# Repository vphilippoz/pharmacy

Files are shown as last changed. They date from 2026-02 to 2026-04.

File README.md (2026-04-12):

# Pharmacy Cross Display
<p align="left">
    <a href="https://github.com/vphilippoz/pharmacy/releases/tag/v1.1" alt="Latest stable version">
        </a>
</p>

A miniature pharmacy cross display made of LED matrices.

<p align="center">
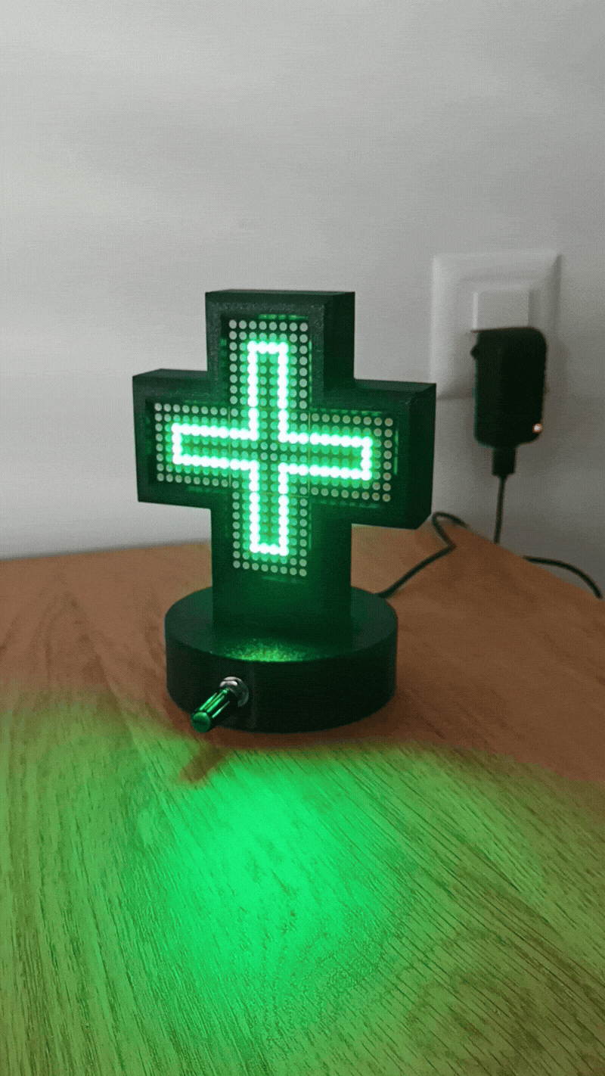
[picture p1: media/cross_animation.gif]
    
</p>

This is a fun project to build and decorate you home, or bring at a rave party! The software runs on a ESP32 and controls 5 square LED matrices.

# Features

In its current version, the project has:

- 8 animations
- Button to switch between animations
- Potentiometer to tune brightness and animation speed
- Python script to easily create animation bitmap from a .gif file
- Excel file to easily create animation bitmap from a drawing (in excel file)

Available animations are:

1. Always ON
1. Blink
1. Random (White noise)
1. Cross shrinking
1. Girl dance
1. Fortnite dance
1. Spinning fish
1. Spiral

# Usage

Plug the power connector. The device starts automatically. A short press on the button changes the animation. Turning the knob allows to tune the animation speed. One cycle is between 80 BPM and 250 BPM. When holding the button, the knob controlls the display brightness.

# BOM

This list is not intended to be a shopping list. It enumerates everything needed to make the Pharmacy Cross Display, but use what you have and adapt the design as needed.

## Electronics

<p align="center">
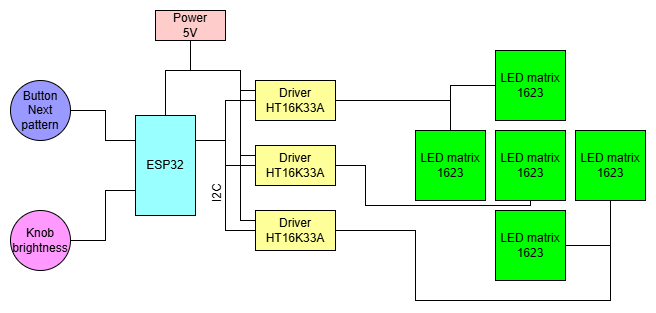
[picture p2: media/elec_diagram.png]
    
</p>

- 5V power supply
- Custom-made PCBs (one of each)
- ESP32-C6-DevKit
- 3 HT16K33 modules (Adafruit 1427)
- 5 green LED matrices (Adafruit 1623)
- 1 10kOhm rotary potentiometer
- 1 THT 10kOhm resistor
- 1 push button
- 1 barrel power connector
- Cables
- Headers for ESP32, HT16k33 and peripherals

## Casing

- 4-parts 3D printed custom casing. I printed mine in black PETG.
- 2 M2.5x4 socket head cap screws
- 10 M2.5x8 socket head cap screws
- Optional: 6 M2.5 washers

## Tools

- 3D printer
- 2mm allen key
- Soldering iron
- Solder
- Set of pliers

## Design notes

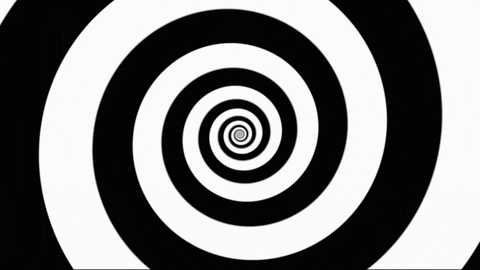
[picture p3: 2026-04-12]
media/gifs/spiral.gif

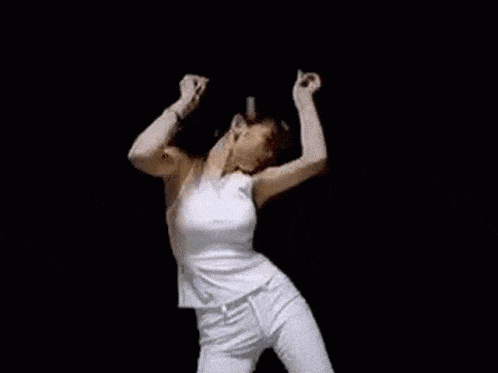
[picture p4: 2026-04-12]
media/gifs/girl.gif

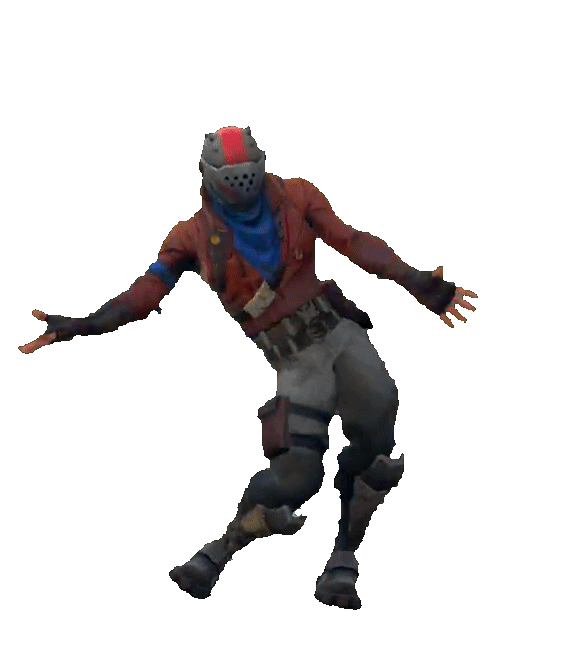
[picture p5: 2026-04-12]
media/gifs/fortnite.gif

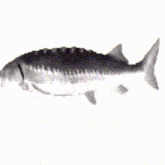
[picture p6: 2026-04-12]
media/gifs/fish.gif

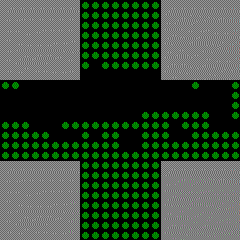
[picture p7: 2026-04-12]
Software/animation_library/fish_animation.gif

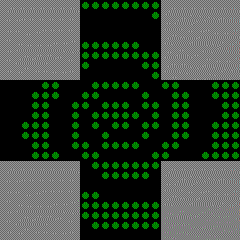
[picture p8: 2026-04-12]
Software/animation_library/spiral_animation.gif

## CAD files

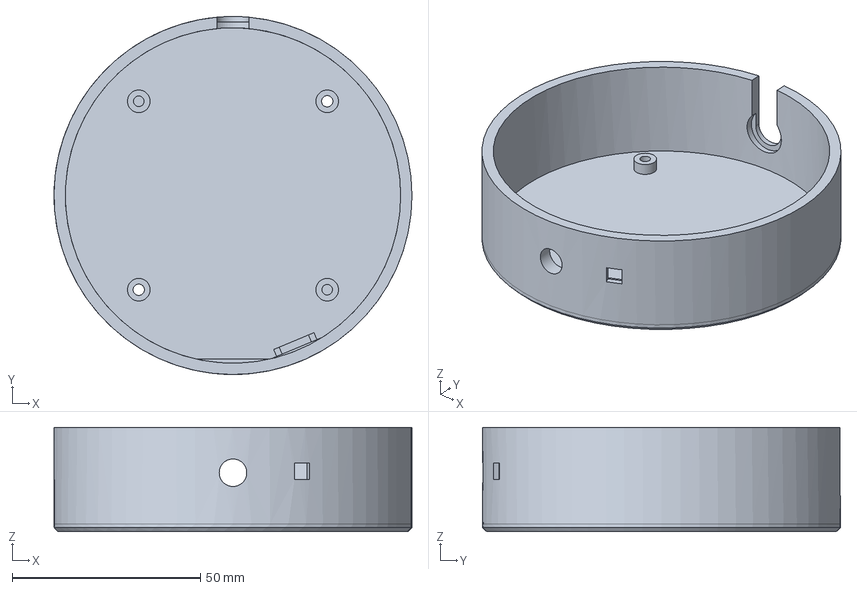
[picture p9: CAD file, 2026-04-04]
3D/case_logic_bottom.FCStd
95.0 x 95.0 x 27.6 mm

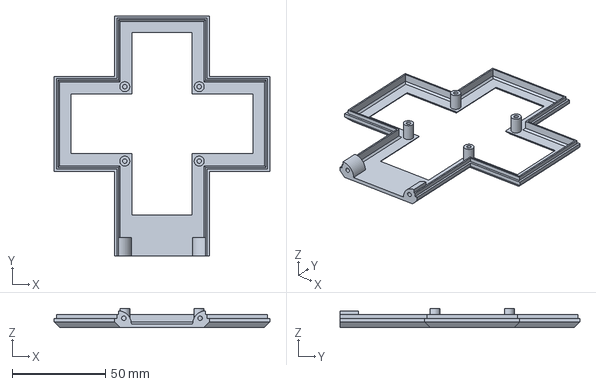
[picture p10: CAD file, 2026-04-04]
3D/case_cross_top.FCStd
116.0 x 129.0 x 10.3 mm

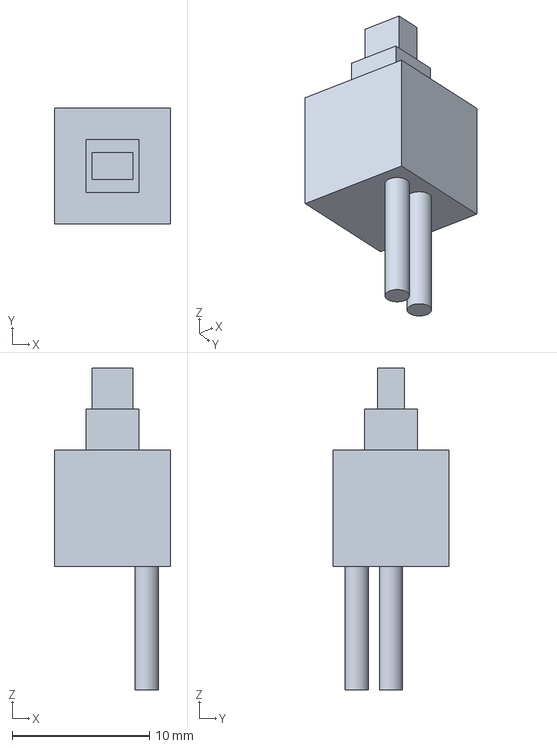
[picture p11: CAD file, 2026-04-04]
3D/button.FCStd
8.50 x 8.50 x 23.5 mm

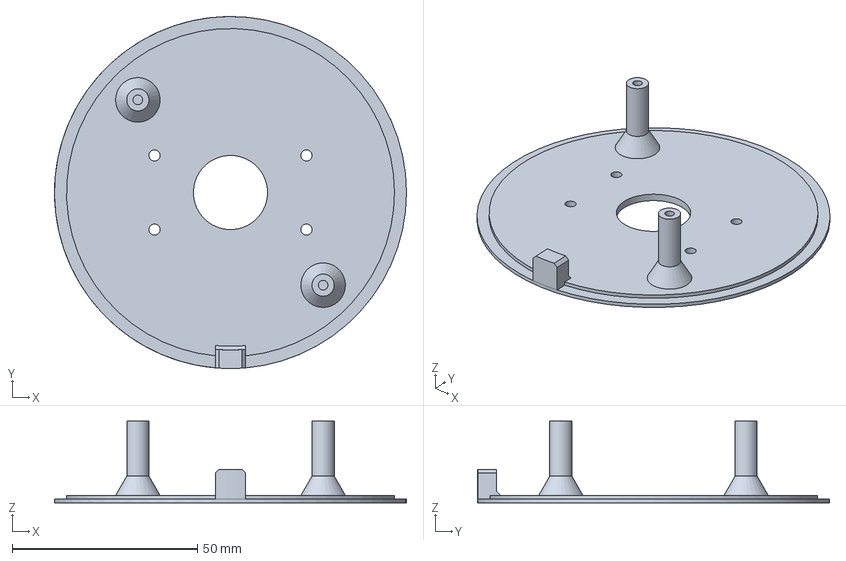
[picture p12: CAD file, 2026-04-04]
3D/case_logic_top.FCStd
95.0 x 95.0 x 22.0 mm

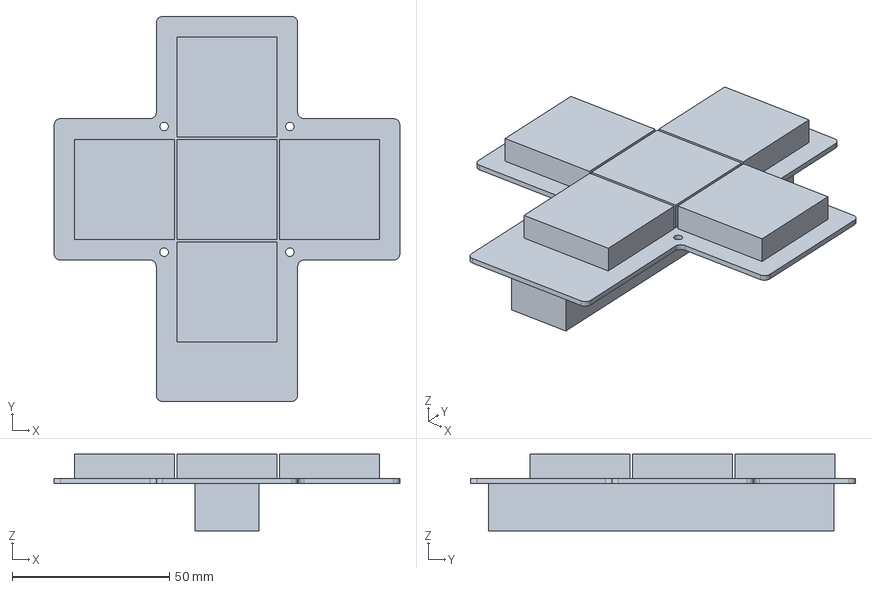
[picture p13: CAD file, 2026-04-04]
3D/PCB_cross.FCStd
110.0 x 122.5 x 24.4 mm

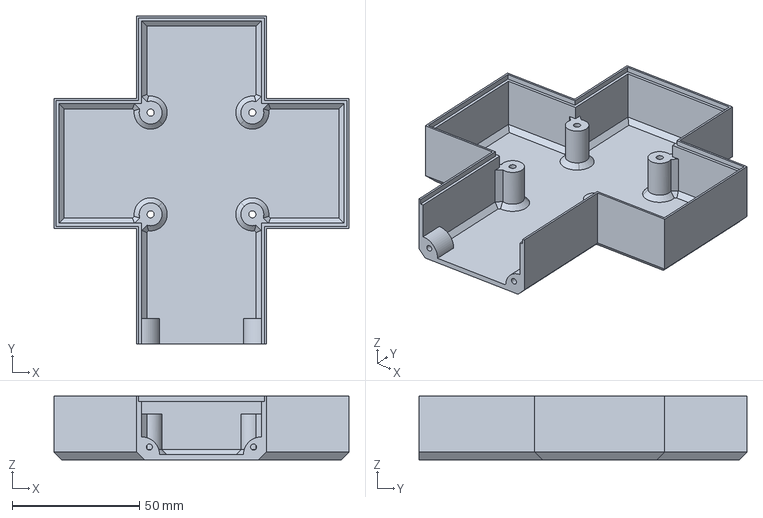
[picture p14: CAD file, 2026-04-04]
3D/case_cross_bottom.FCStd
116.0 x 129.0 x 25.0 mm

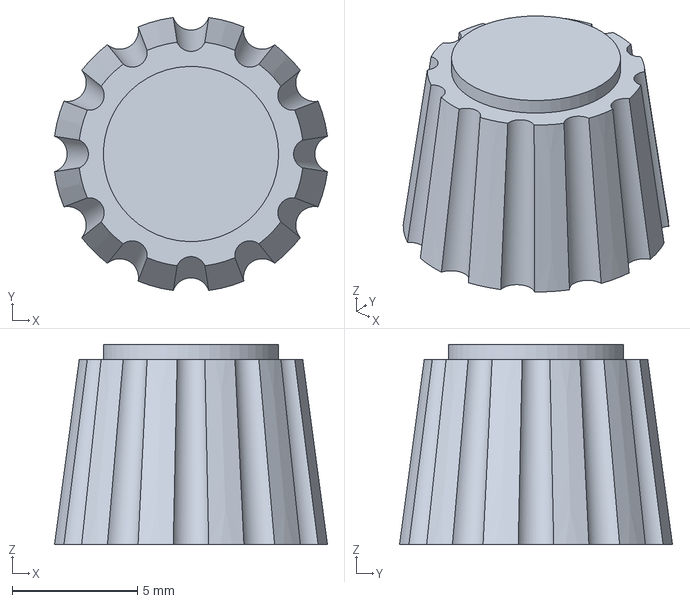
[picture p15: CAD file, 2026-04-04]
3D/knob_btn.FCStd
10.9 x 10.9 x 8.00 mm

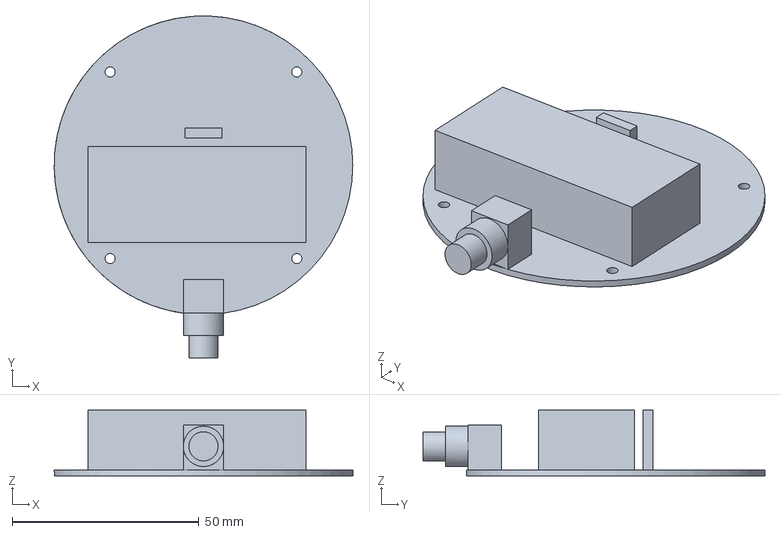
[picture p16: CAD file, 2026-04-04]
3D/PCB_logic.FCStd
80.0 x 91.6 x 17.6 mm

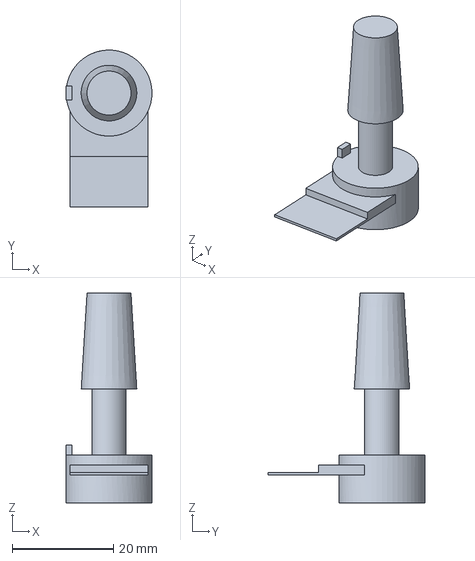
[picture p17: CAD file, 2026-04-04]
3D/potentiometer.FCStd
17.0 x 31.0 x 41.5 mm

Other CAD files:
3D/asm.FCStd
3D/case_cross_bottom.stl
3D/case_cross_top.stl
3D/case_logic_bottom.stl
3D/case_logic_top.stl

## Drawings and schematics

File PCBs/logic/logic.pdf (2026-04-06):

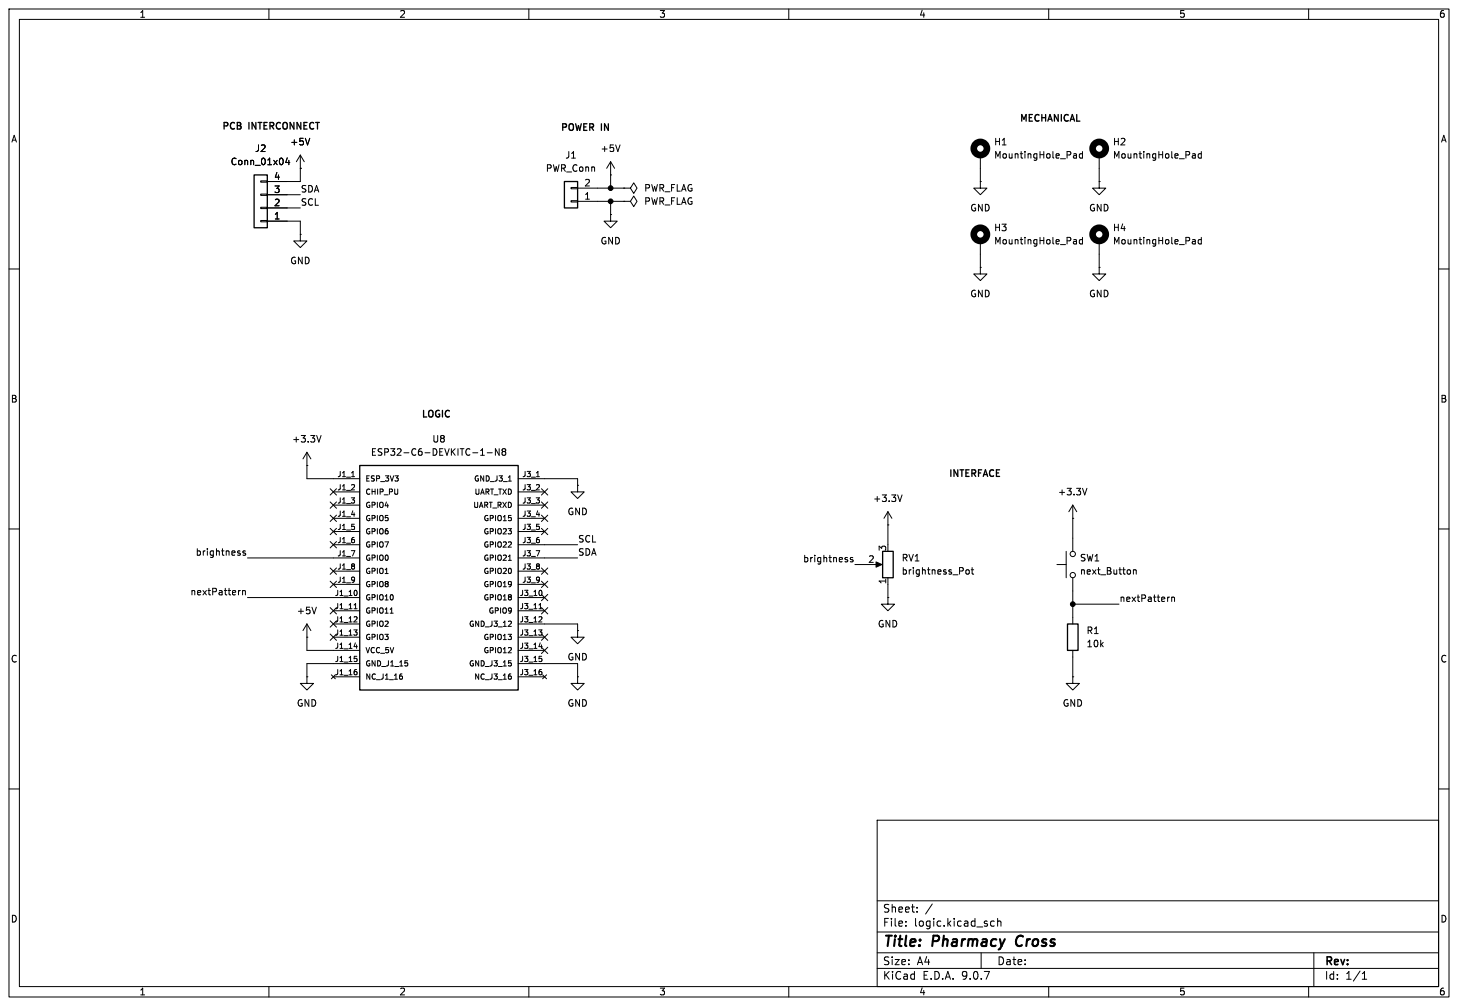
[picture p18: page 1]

File: logic.kicad_sch Sheet: /
Id: 1/1 Title: Pharmacy Cross

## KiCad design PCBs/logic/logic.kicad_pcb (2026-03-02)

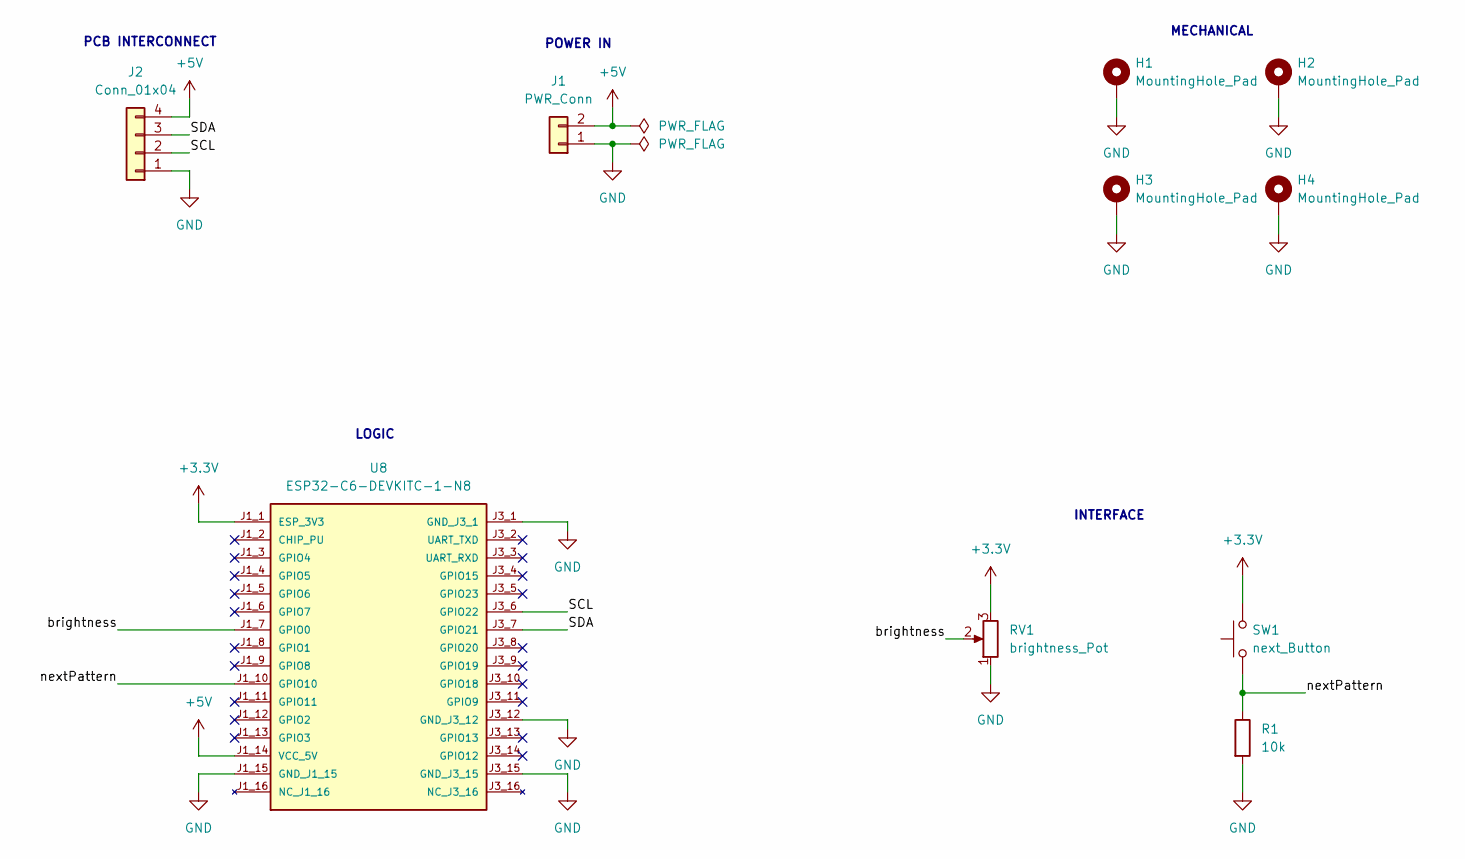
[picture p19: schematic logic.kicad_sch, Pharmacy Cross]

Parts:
H1, H2, H3, H4: MountingHole_Pad; MountingHole_2.7mm_M2.5_ISO7380_Pad
J1: PWR_Conn; BarrelJack_Horizontal
J2: Conn_01x04; PinHeader_1x04_P2.54mm_Vertical
R1: 10k; R_Axial_DIN0207_L6.3mm_D2.5mm_P10.16mm_Horizontal
RV1: brightness_Pot; PinHeader_1x03_P2.54mm_Vertical
SW1: next_Button; PinHeader_1x02_P2.54mm_Vertical
U8: ESP32-C6-DEVKITC-1-N8; MODULE_ESP32-C6-DEVKITC-1-N8; PARTREV 1.3

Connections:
+3.3V: RV1.3, SW1.2, U8.J1_1 (ESP_3V3)
+5V: J1.2, J2.4, U8.J1_14 (VCC_5V)
/SCL: J2.2, U8.J3_6 (GPIO22)
/SDA: J2.3, U8.J3_7 (GPIO21)
/brightness: RV1.2, U8.J1_7 (GPIO0)
/nextPattern: R1.1, SW1.1, U8.J1_10 (GPIO10)
GND: H1.1, H2.1, H3.1, H4.1, J1.1, J2.1, R1.2, RV1.1, U8.J1_15 (GND_J1_15), U8.J3_1 (GND_J3_1), U8.J3_12 (GND_J3_12), U8.J3_15 (GND_J3_15)

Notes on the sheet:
LOGIC
PCB INTERCONNECT
POWER IN
INTERFACE
MECHANICAL

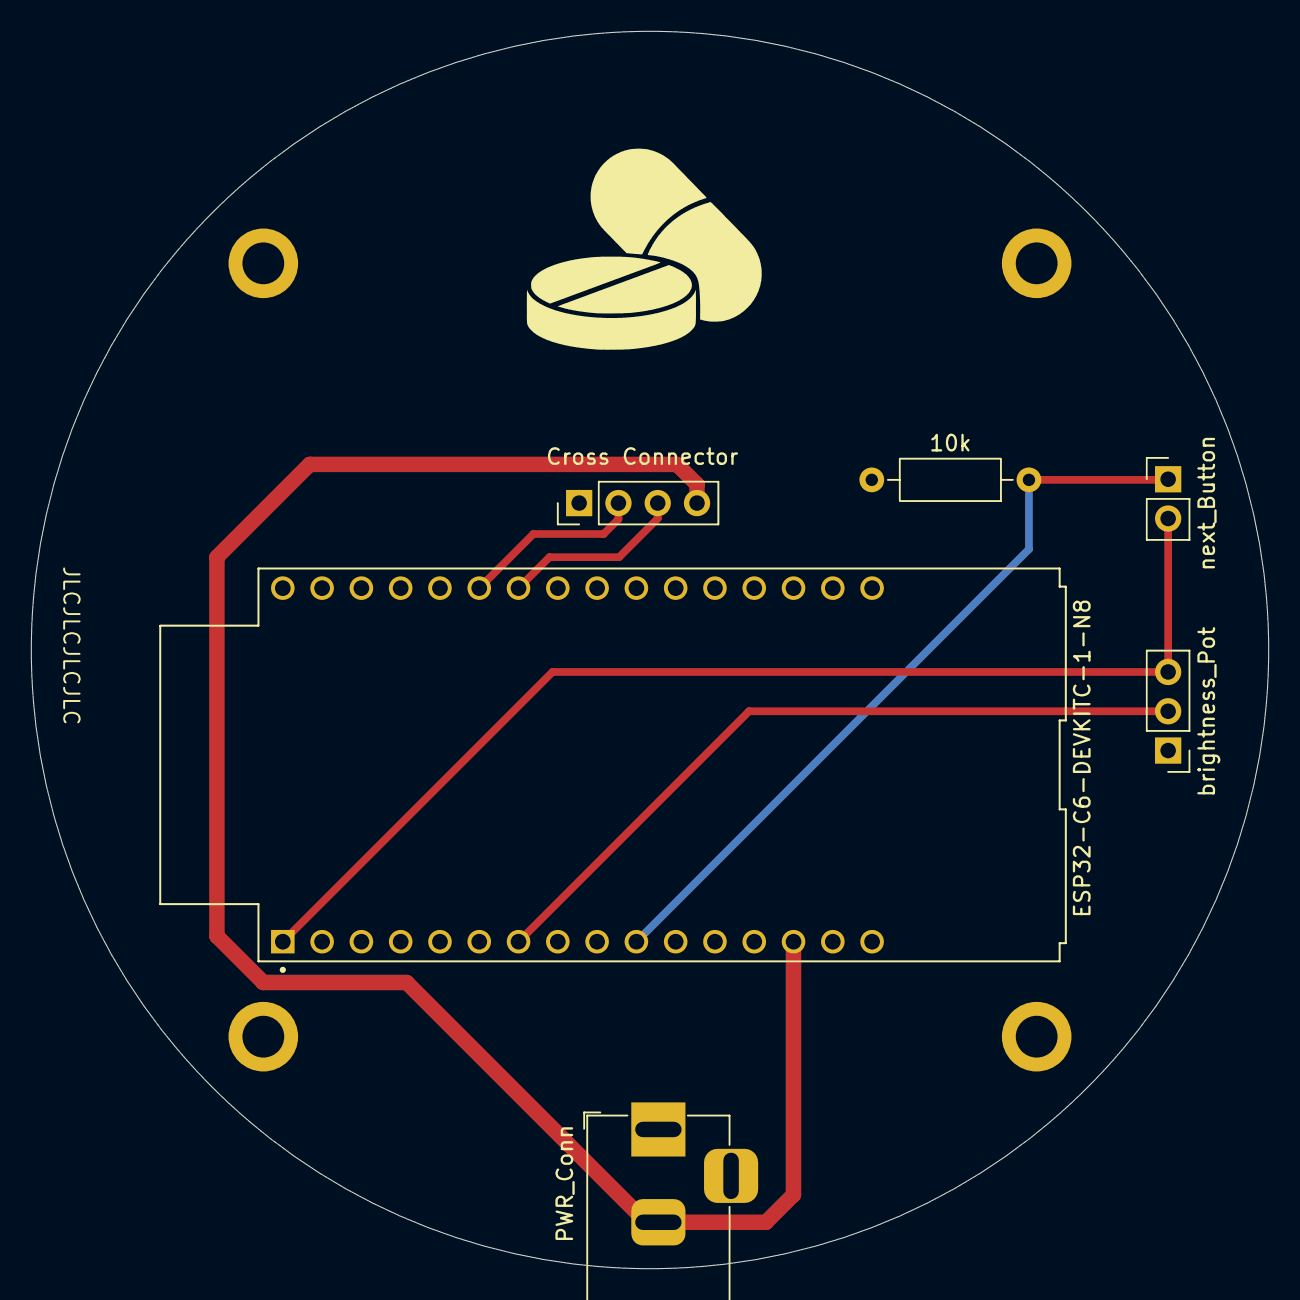
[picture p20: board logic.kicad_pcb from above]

Board: 2 copper layers, 80.0 x 80.0 mm, 10 parts (0 on the bottom side), 7 nets.

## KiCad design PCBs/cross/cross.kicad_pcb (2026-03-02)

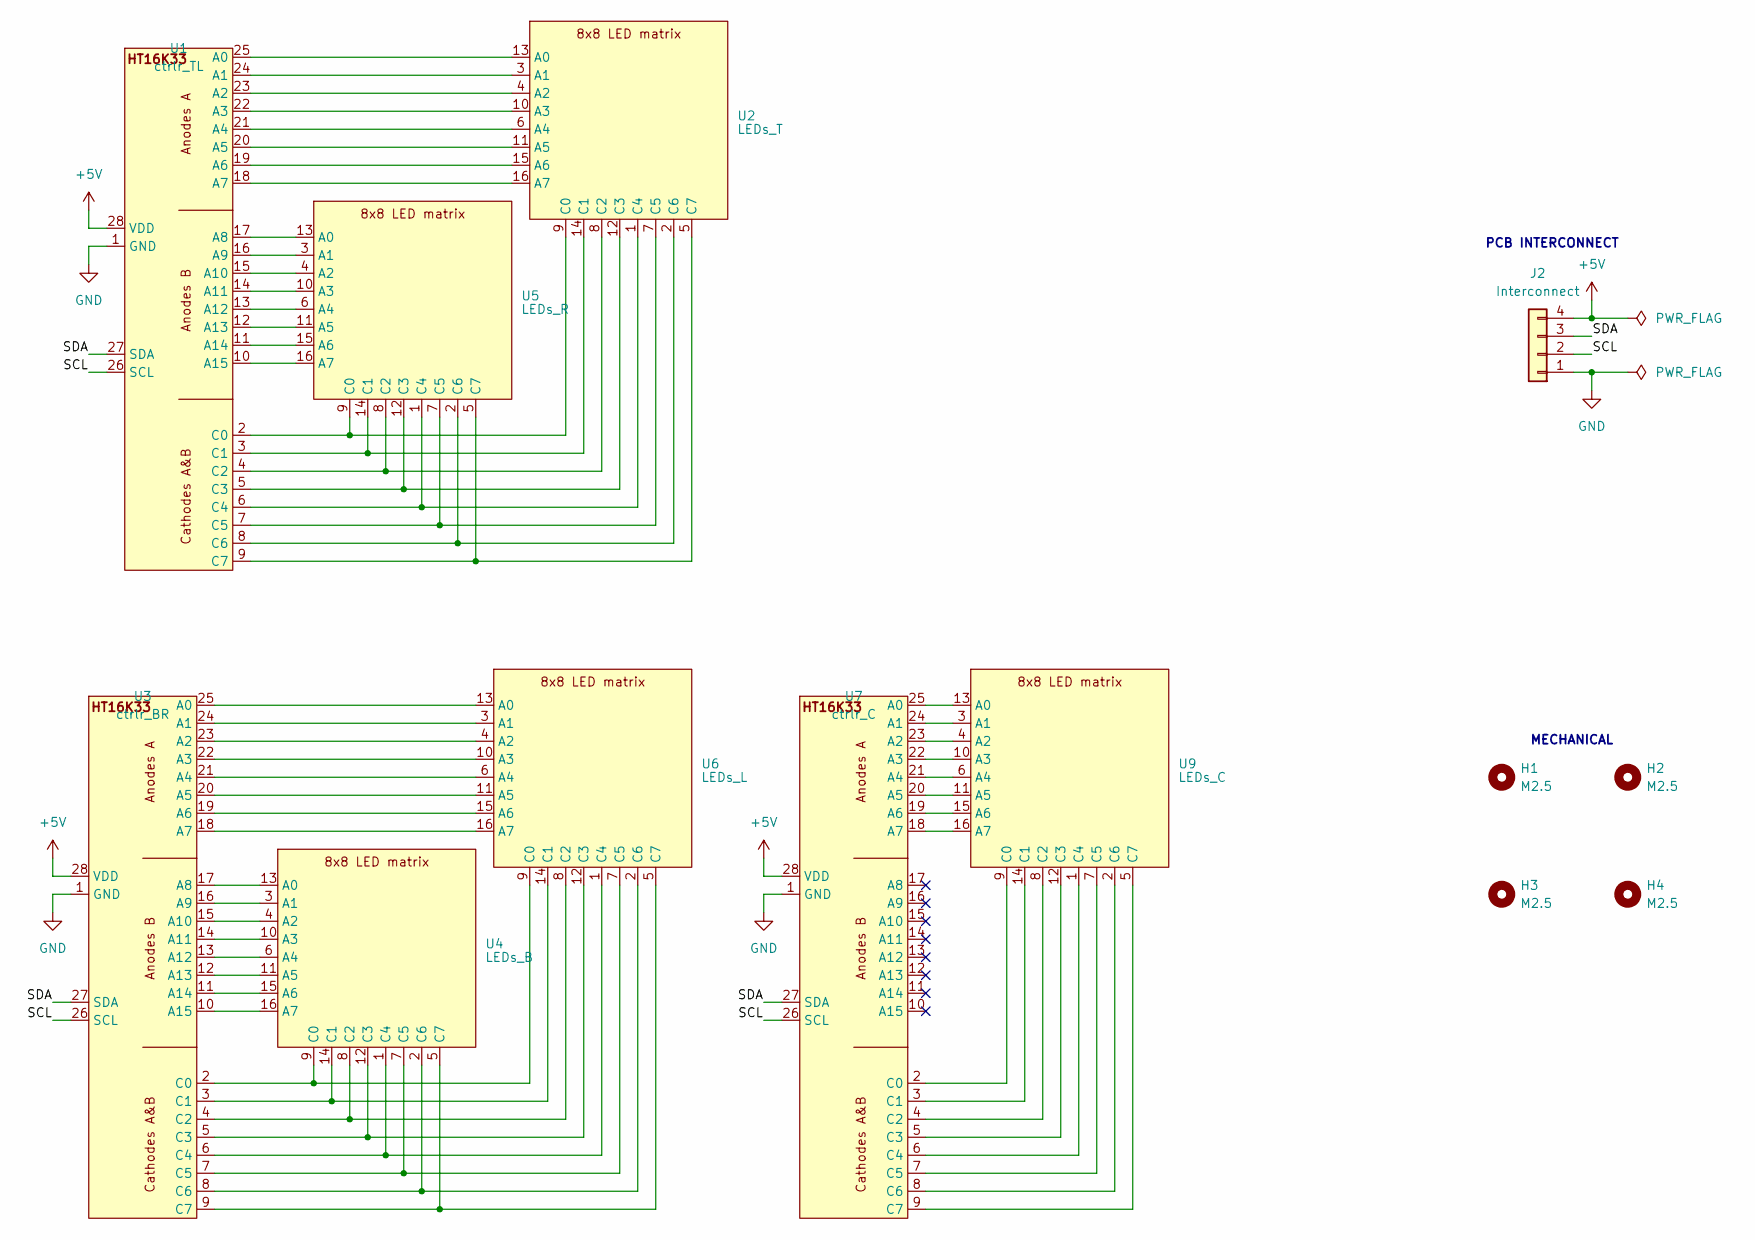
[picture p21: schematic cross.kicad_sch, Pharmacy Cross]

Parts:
H1, H2, H3, H4: M2.5; MountingHole_2.7mm_M2.5
J2: Interconnect; PinHeader_1x04_P2.54mm_Vertical
U1: ctrlr_TL; HT16K33
U2: LEDs_T; KWM-30881
U3: ctrlr_BR; HT16K33
U4: LEDs_B; KWM-30881
U5: LEDs_R; KWM-30881
U6: LEDs_L; KWM-30881
U7: ctrlr_C; HT16K33
U9: LEDs_C; KWM-30881

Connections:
+5V: J2.4, U1.28 (VDD), U3.28 (VDD), U7.28 (VDD)
/SCL: J2.2, U1.26 (SCL), U3.26 (SCL), U7.26 (SCL)
/SDA: J2.3, U1.27 (SDA), U3.27 (SDA), U7.27 (SDA)
GND: J2.1, U1.1 (GND), U3.1 (GND), U7.1 (GND)
unnamed: U1.25 (A0), U2.13 (A0)
unnamed: U1.24 (A1), U2.3 (A1)
unnamed: U1.23 (A2), U2.4 (A2)
unnamed: U1.22 (A3), U2.10 (A3)
unnamed: U1.21 (A4), U2.6 (A4)
unnamed: U1.20 (A5), U2.11 (A5)
unnamed: U1.19 (A6), U2.15 (A6)
unnamed: U1.18 (A7), U2.16 (A7)
unnamed: U1.17 (A8), U5.13 (A0)
unnamed: U1.16 (A9), U5.3 (A1)
unnamed: U1.15 (A10), U5.4 (A2)
unnamed: U1.14 (A11), U5.10 (A3)
unnamed: U1.13 (A12), U5.6 (A4)
unnamed: U1.12 (A13), U5.11 (A5)
unnamed: U1.11 (A14), U5.15 (A6)
unnamed: U1.10 (A15), U5.16 (A7)
unnamed: U1.2 (C0), U2.9 (C0), U5.9 (C0)
unnamed: U1.3 (C1), U2.14 (C1), U5.14 (C1)
unnamed: U1.4 (C2), U2.8 (C2), U5.8 (C2)
unnamed: U1.5 (C3), U2.12 (C3), U5.12 (C3)
unnamed: U1.6 (C4), U2.1 (C4), U5.1 (C4)
unnamed: U1.7 (C5), U2.7 (C5), U5.7 (C5)
unnamed: U1.8 (C6), U2.2 (C6), U5.2 (C6)
unnamed: U1.9 (C7), U2.5 (C7), U5.5 (C7)
unnamed: U3.25 (A0), U6.13 (A0)
unnamed: U3.24 (A1), U6.3 (A1)
unnamed: U3.23 (A2), U6.4 (A2)
unnamed: U3.22 (A3), U6.10 (A3)
unnamed: U3.21 (A4), U6.6 (A4)
unnamed: U3.20 (A5), U6.11 (A5)
unnamed: U3.19 (A6), U6.15 (A6)
unnamed: U3.18 (A7), U6.16 (A7)
unnamed: U3.17 (A8), U4.13 (A0)
unnamed: U3.16 (A9), U4.3 (A1)
unnamed: U3.15 (A10), U4.4 (A2)
unnamed: U3.14 (A11), U4.10 (A3)
unnamed: U3.13 (A12), U4.6 (A4)
unnamed: U3.12 (A13), U4.11 (A5)
unnamed: U3.11 (A14), U4.15 (A6)
unnamed: U3.10 (A15), U4.16 (A7)
unnamed: U3.2 (C0), U4.9 (C0), U6.9 (C0)
unnamed: U3.3 (C1), U4.14 (C1), U6.14 (C1)
unnamed: U3.4 (C2), U4.8 (C2), U6.8 (C2)
unnamed: U3.5 (C3), U4.12 (C3), U6.12 (C3)
unnamed: U3.6 (C4), U4.1 (C4), U6.1 (C4)
unnamed: U3.7 (C5), U4.7 (C5), U6.7 (C5)
unnamed: U3.8 (C6), U4.2 (C6), U6.2 (C6)
unnamed: U3.9 (C7), U4.5 (C7), U6.5 (C7)
unnamed: U7.25 (A0), U9.13 (A0)
unnamed: U7.24 (A1), U9.3 (A1)
unnamed: U7.23 (A2), U9.4 (A2)
unnamed: U7.22 (A3), U9.10 (A3)
unnamed: U7.21 (A4), U9.6 (A4)
unnamed: U7.20 (A5), U9.11 (A5)
unnamed: U7.19 (A6), U9.15 (A6)
unnamed: U7.18 (A7), U9.16 (A7)
unnamed: U7.2 (C0), U9.9 (C0)
unnamed: U7.3 (C1), U9.14 (C1)
unnamed: U7.4 (C2), U9.8 (C2)
unnamed: U7.5 (C3), U9.12 (C3)
unnamed: U7.6 (C4), U9.1 (C4)
unnamed: U7.7 (C5), U9.7 (C5)
unnamed: U7.8 (C6), U9.2 (C6)
unnamed: U7.9 (C7), U9.5 (C7)

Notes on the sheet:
PCB INTERCONNECT
MECHANICAL

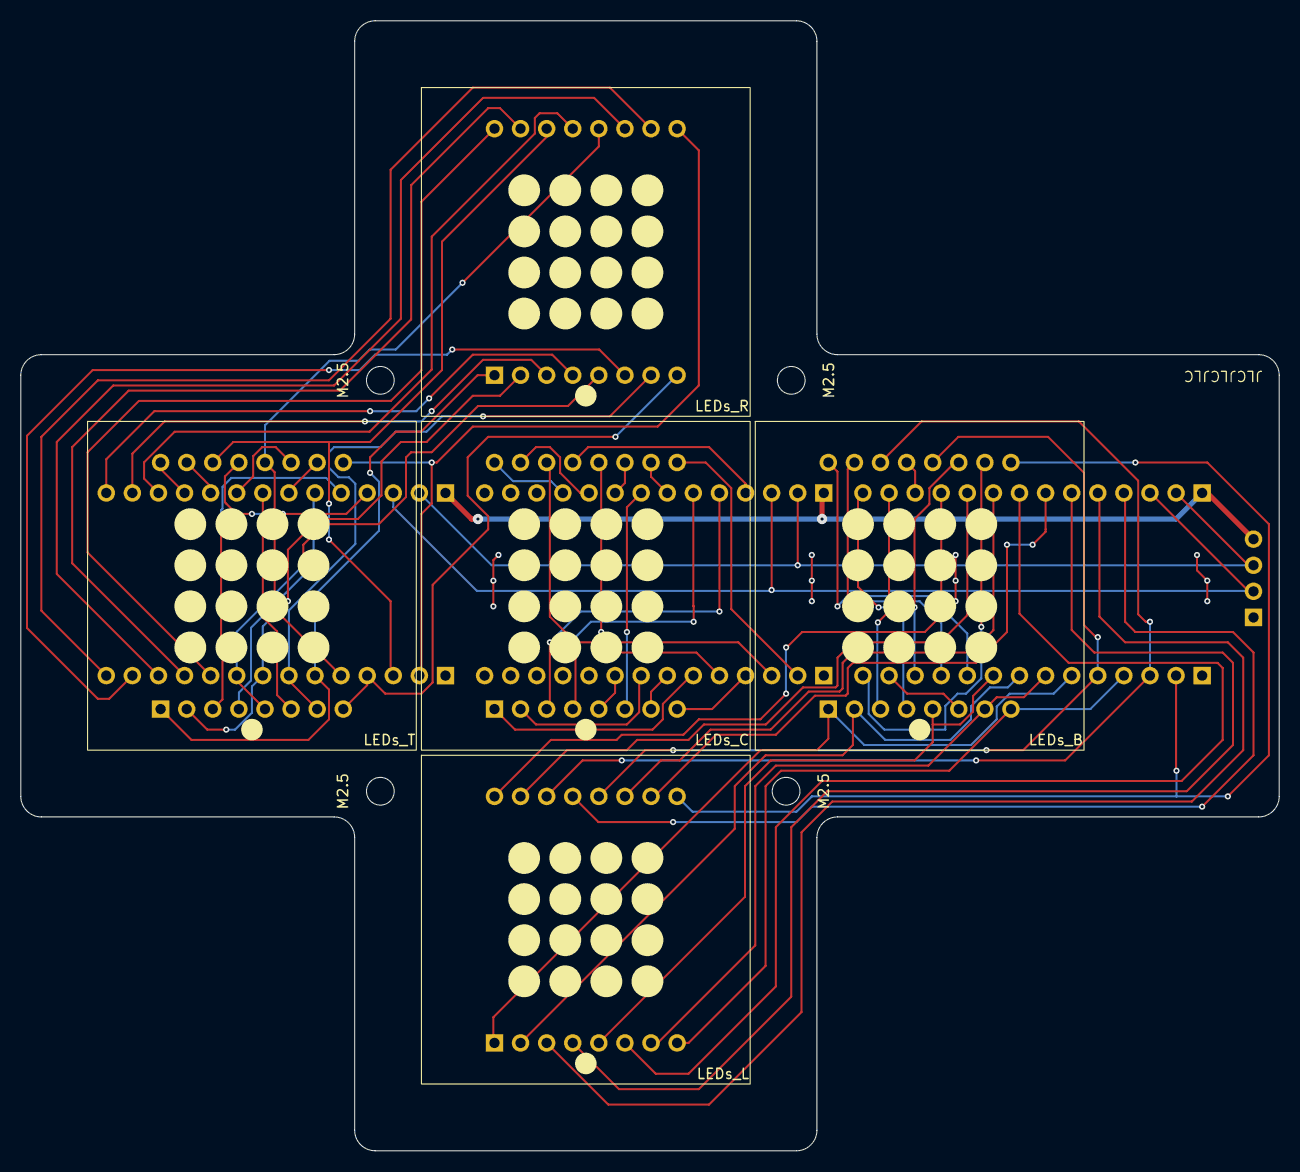
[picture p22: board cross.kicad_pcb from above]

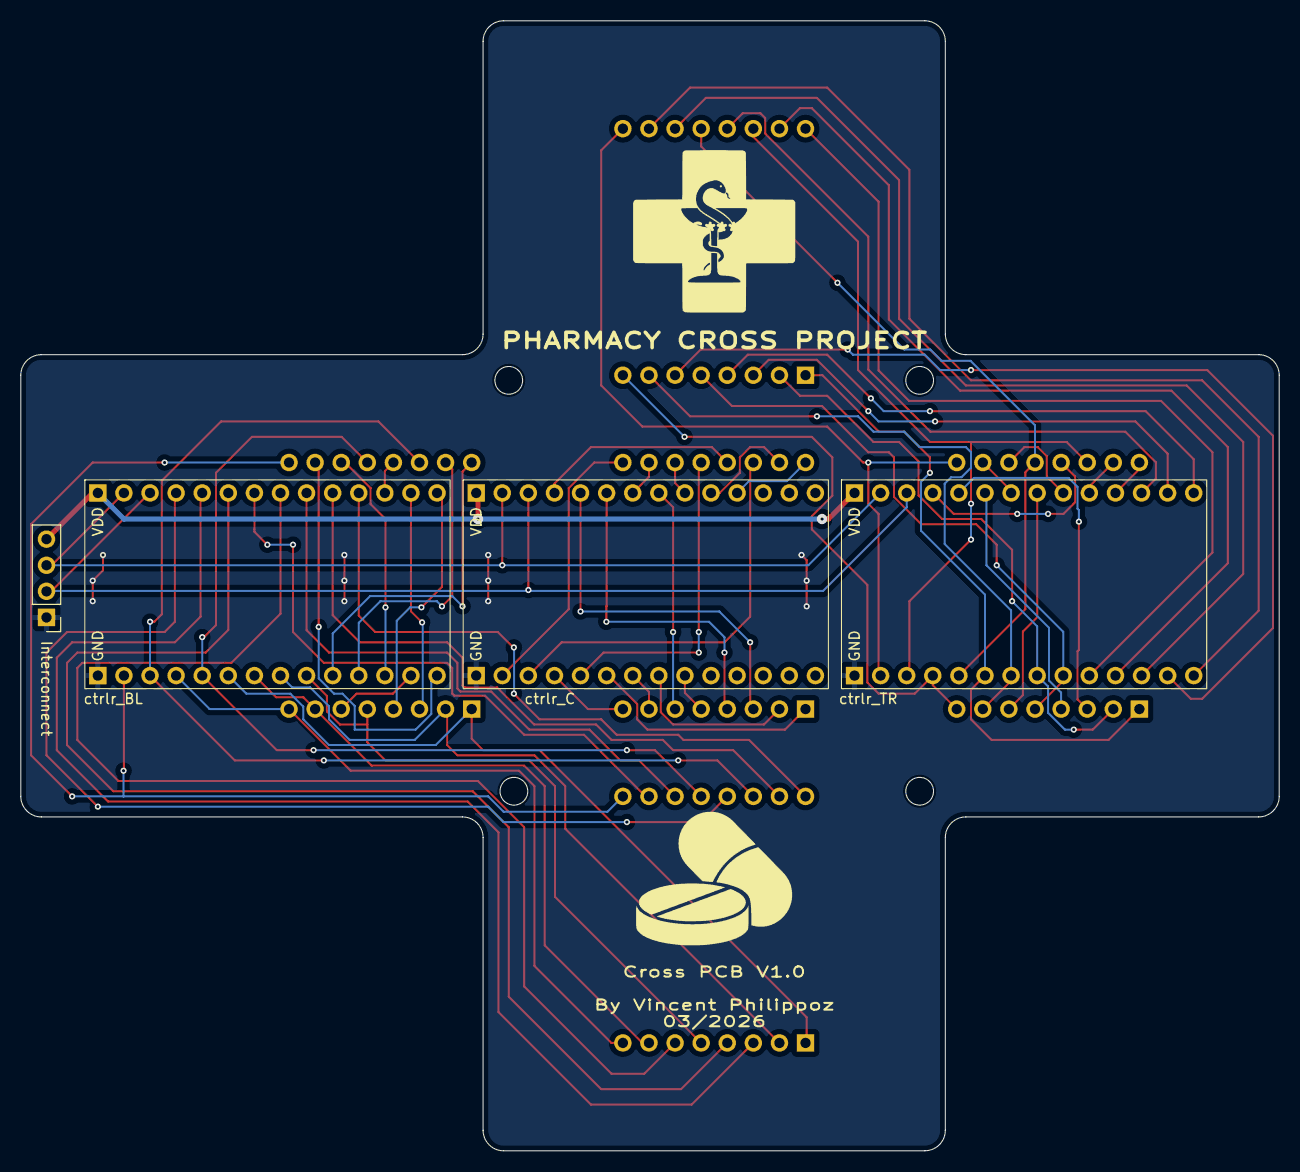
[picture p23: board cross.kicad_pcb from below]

Board: 2 copper layers, 122.5 x 110.0 mm, 13 parts (4 on the bottom side), 68 nets.

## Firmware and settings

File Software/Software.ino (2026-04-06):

/*
  Software.ino - Main code for the Pharmacy cross project.
  Created by Vincent Philippoz.

  This code is made for the ESP32-C6 platform and is intended to be used with the custom PCBs.
*/

#include "src\animation\animation.hpp"
#include "src\peripherals\peripherals.hpp"

// Constants
constexpr unsigned int SERIAL_BAUD_RATE = 115200;
constexpr bool DEBUG = false;

void setup() {
    // Initialize serial communication
    if(DEBUG) {
        Serial.begin(SERIAL_BAUD_RATE);
    }

    // Initialize modules
    peripherals::setup(DEBUG);
    animation::setup(DEBUG);
}

void loop() {
    static bool change_anim = false;
    static unsigned long last_frame_change_time = 0; 
    static uint16_t speed = peripherals::get_speed();
    static uint8_t brightness = peripherals::get_brightness();

    // Get user inputs
    uint8_t tmp_brightness = peripherals::get_brightness();
    speed = peripherals::get_speed();

    // Update brightness
    if(tmp_brightness != brightness) {
        brightness = tmp_brightness;
        peripherals::set_brightness(brightness);
    }

    // Update animation if required
    if(peripherals::get_next_animation_required()) {
        animation::select_next_animation();
    }
    
    // Display the next frame of the current animation if the required time has passed
    uint16_t now = millis();
    uint16_t time_between_frames = speed / animation::get_animation_frame_count();
    if (now - last_frame_change_time >= time_between_frames) {
        last_frame_change_time = now;
        std::vector<std::vector<uint16_t>> frame = animation::get_next_frame();
        peripherals::set_frame(frame);
    }

    // Run loop at a reasonable speed
    delay(20); // [ms]
}

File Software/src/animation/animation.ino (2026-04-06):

/*
Minimal version to test the module.

This code is a minimal version to test the module. It toggles the defined GPIOs and the corresponding LED color.
*/

#include "animation.hpp"

// Constants
constexpr unsigned int SERIAL_BAUD_RATE = 115200;
constexpr bool VERBOSE = true;
uint8_t frame_counter = 0; 


void setup() {
    if(VERBOSE) {
        // Open serial communications on the native USB port
        Serial.begin(SERIAL_BAUD_RATE);while(!Serial);
    }

    // Setup the library
    animation::setup(VERBOSE);
    if(VERBOSE) {Serial.println("Setup complete");}
}

void loop() {
    // Get and print the next frame of the animation
    std::vector<std::vector<uint16_t>> frame = animation::get_next_frame();
    if(VERBOSE) {
        Serial.print("Current animation ID: ");
        Serial.println(animation::get_animation_id());
        Serial.print("Current animation speed: ");
        Serial.println(animation::get_animation_speed());
        for (size_t i = 0; i < frame.size(); i++) {
            Serial.print("Panel ");
            Serial.print(i);
            Serial.print(": ");
            for (size_t j = 0; j < frame[i].size(); j++) {
                Serial.print(frame[i][j], HEX);
                Serial.print(" ");
            }
            Serial.println();
        }
    }
    ++frame_counter;
    
    // After a few frames, switch to the next animation
    if(frame_counter >= 5) {
        current_animation_id++; // Increment animation id
        animation::set_next_animation();
        frame_counter = 0; // Reset frame counter
    }
    
    delay(animation::get_animation_speed()/animation::get_animation_frame_count()); // Wait for the animation speed duration
}

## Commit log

2026-02-15 Apply KiCad gitignore
2026-02-15 Current state of design
    [pharmacy.kicad_pcb, pharmacy.kicad_sch]
2026-02-15 Added mounting holes to PCB
    [pharmacy.kicad_pcb, pharmacy.kicad_sch]
2026-02-18 Split PCB in two : cross + logic
    [cross.kicad_pcb, cross.kicad_sch, logic.kicad_pcb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]
2026-02-18 Logic PCB finished
    [logic.kicad_pcb, logic.kicad_sch]
2026-02-19 Cross routing 1/3 done
    [cross.kicad_pcb, cross.kicad_sch]
2026-02-21 Cross routing 2/3 done
    [cross.kicad_pcb]
2026-03-02 Added Digit display + animation creator
    [img_creator.xlsx]
2026-03-02 Added shrinking animation
    [img_creator.xlsx]
2026-03-02 Improved frame printing in console
2026-03-02 Fixed pannels rotation to match PCB
    [img_creator.xlsx]
2026-03-02 Finished PCBs, ready to order
    [cross.kicad_pcb, cross.kicad_sch, logic.kicad_pcb]
2026-03-10 Works on PCB except animation mapping reversed (MSB->LSB should be LSB->MSB)
    [Software.ino, peripherals.cpp, peripherals.hpp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]
2026-03-16 Image creator fixed
    [img_creator.xlsx]
2026-03-16 Animations fixed, debouncing btn needed
    [Software.ino, peripherals.cpp, peripherals.hpp]
2026-03-16 minor change
    [img_creator.xlsx]
2026-03-16 3D of manufactured PCBs
    [PCB_cross.FCStd, PCB_logic.FCStd]
2026-03-23 Cross case done
    [PCB_cross.FCStd, PCB_logic.FCStd, asm2.FCStd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]
2026-03-23 Logic casing without pot&button
    [PCB_cross.FCStd, PCB_logic.FCStd, asm2.FCStd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]
2026-03-23 Finished 3D, logic to print
    [asm2.FCStd, button.FCStd, case_logic_bottom.FCStd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]
2026-04-01 Logic works
    [PCB_logic.FCStd, asm2.FCStd, case_logic_bottom.FCStd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]
2026-04-04 Added locator to logic top
    [asm2.FCStd, case_logic_bottom.FCStd, case_logic_top.FCStd]
2026-04-04 STL upload
    [case_cross_bottom.stl, case_cross_top.stl, case_logic_bottom.stl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]
2026-04-05 Single knob to control speed and brightness works using button to switch. Now make loop at fixed fast rate and change frame only when necessary.
    [peripherals.cpp, peripherals.hpp, peripherals.ino]
2026-04-05 Ok-ish, 2 issues: 1) Btn triggers both at press and release. 2) Should add smarter logic to split press and hold
    [Software.ino, animation.ino, peripherals.hpp]
2026-04-12 Minor edit
    [img_creator.xlsx]
